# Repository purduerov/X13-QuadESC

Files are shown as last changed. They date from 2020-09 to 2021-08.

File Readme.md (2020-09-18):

# Readme for X13-QuadESC

Whenever you make a new part, download the datasheet and save it here _**and**_ with the part in the parts library

Always pull other people's changes before beginning to work
`git pull`

Be sure to push your changes after  working on them. Run:
1. `git add .` to add any files in this directory or a subdirectory
or `git add -u` to add any modified files
2. (Optional) `git clean -nX` to see what ignored files can be removed
	`git clean -fX` removes ignored files (Eagle backups)
3. `git commit -m "helpful commit message"` with a description of the work that you did
4. `git push` to push your work to github

Other helpful commands
* `git status` says information about modified and staged files
* `git log` shows the recent commits of the repository
* `git log filename.extension` show the recent commits for just that file
* `git checkout first-couple-letter-of-commit-id` lets you go back to a previous version
* `git checkout master` brings you back to the latest commit
* `git tag` lists the tags
* `git tag -a orderX -m "the version of the board placed for the X'th order"` tag a specific commit
* `git push --tags` needed to push tags to remote
* `git show orderX` show the commit log for the given tag
* `git checkout orderX` go back and interact with the files at the tagged commit

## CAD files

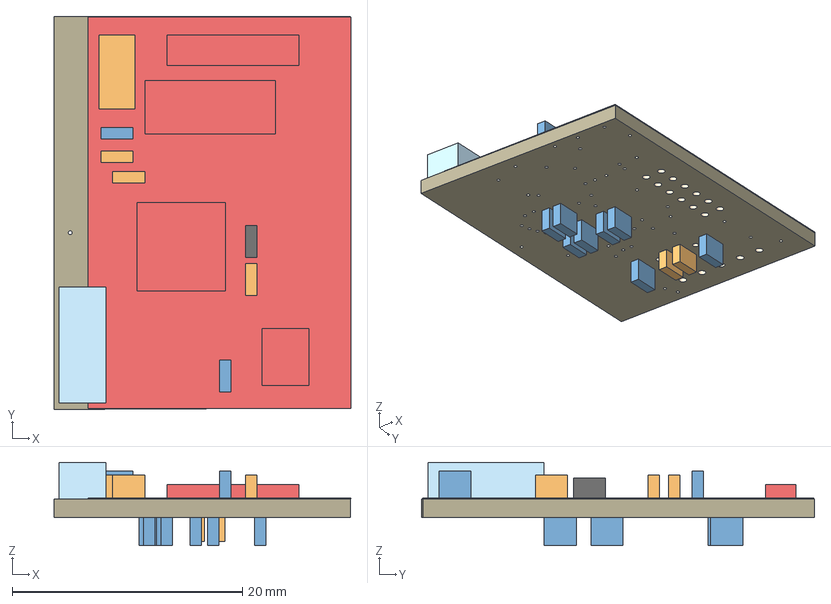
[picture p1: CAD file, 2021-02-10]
Quad_ESC_controller.step
25.8 x 34.2 x 7.23 mm
Board
20pF x 10
LED-0603
10k x 5
DISCRETECOMPONENTS_SWITCH
FE05-1
STM32F042K6T6
TCAN337D
ECS-80-S-4X
JST-8PIN
BACKPLANE_CONNECTORSESC

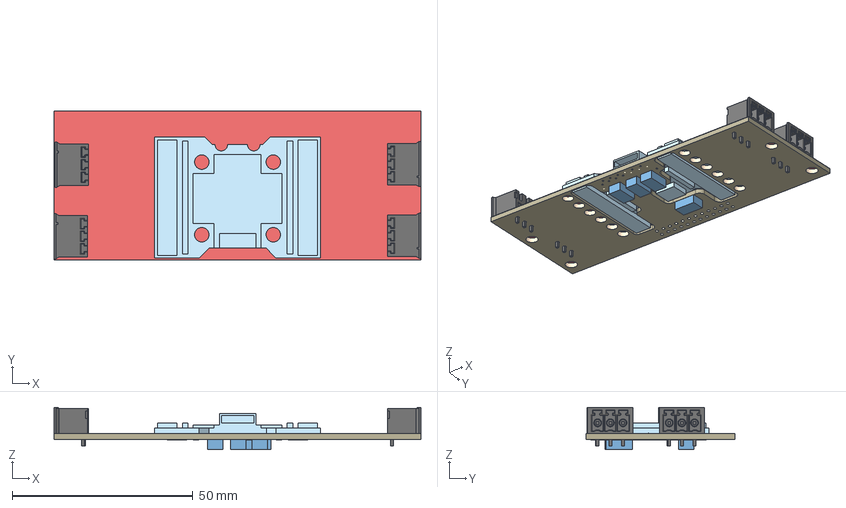
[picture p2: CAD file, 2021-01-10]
Quad_ESC_adapter.step
101.6 x 41.1 x 11.6 mm
Board
LUMENIER_QUAD
150uF x 4
6-32-HOLE x 4
BACKPLANE_ESC_ADAPTER_PWRESC

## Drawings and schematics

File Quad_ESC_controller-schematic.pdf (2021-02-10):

# GND ⁺³V³ +3V³

A

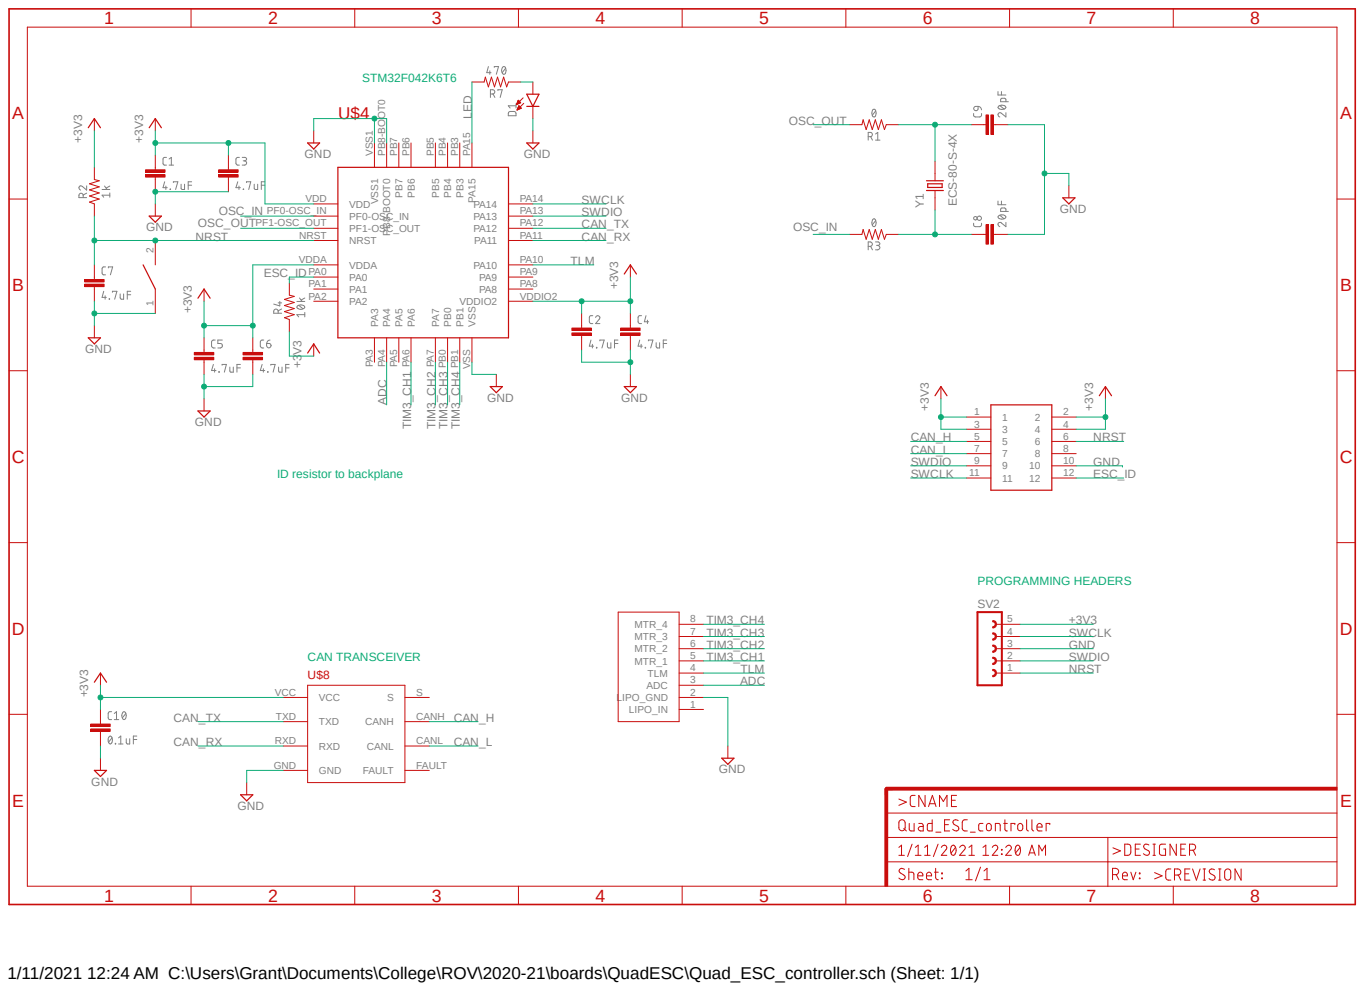
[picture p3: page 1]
GND; GND ⁺³V³ +3V³; GND +3V³; ECS⁻⁸⁰⁻S⁻⁴X; GND ⁺³V³; NRST NRST; PF1-OSC_OUT PF1-OSC_OUT; PF0-OSC_IN PF0-OSC_IN; VDD VDD; VDDA VDDA PA0 PA0 PA1 PA1; PA⁶ PA⁶ PA⁵ PA⁵ PA⁴ PA⁴ PA³ PA³; PA⁷ PA⁷ PB⁰ PB⁰ PB¹ PB¹ VSS VSS PA11; VDDIO2; VDDIO2 PB⁵ PB⁵ PB⁴ PB⁴ PB³ PB³ PA¹⁵ PA¹⁵ PB⁶ PB⁶ PB⁷ PB⁷ PB⁸⁻BOOT0 PB⁸⁻BOOT0 VSS¹ VSS¹ 1 2; VCC VCC; TXD TXD; RXD RXD; GND GND; CANH; CANL; FAULT; LIPO_IN; LIPO_GND; ADC; TLM; MTR_1; MTR_2; MTR_3; MTR_4; 12GND; CAN_TX; CAN_RX; TIM3_CH1 TIM³_CH¹; TIM3_CH2 TIM³_CH²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

STM32F042K6T6

ID resistor to backplane

1/11/2021 12:24 AM C:\Users\Grant\Documents\College\ROV\2020-21\boards\QuadESC\Quad_ESC_controller.sch (Sheet: 1/1)

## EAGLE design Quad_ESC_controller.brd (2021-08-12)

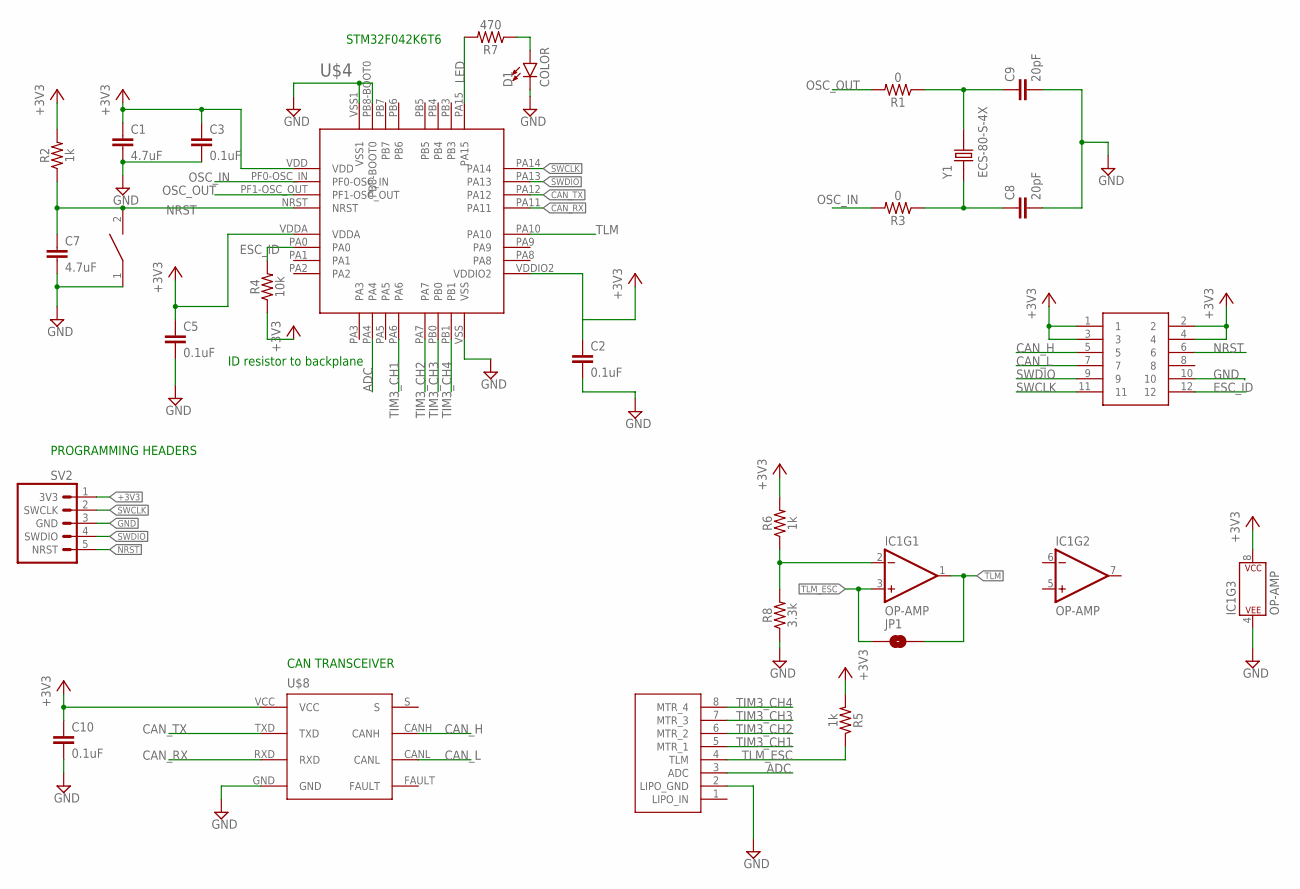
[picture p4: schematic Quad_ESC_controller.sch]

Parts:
C1, C7: 4.7uF; 0603
C2, C3, C5, C10: 0.1uF; 0603
C8, C9: 20pF; 0603
D1: COLOR; 0805
IC1: OP-AMP; SO08
JP1: JUMPER-SMT_2_NO_SILK; SMT-JUMPER_2_NO_SILK
R1, R3: 0; 0603
R2, R5, R6: 1k; 0603
R4: 10k; 0603
R7: 470; 0603
R8: 3.3k; 0603
RESET: DISCRETECOMPONENTS_SWITCH; DISCRETECOMPONENTS_SW_2512
SV2: 3V3 -SWCLK-GND-SWDIO- NRST; 1X05
U$2: JST-8PIN; 8PIN_CONNECTOR
U$3: BACKPLANE_CONNECTORSESC; BACKPLANE_CONNECTORS_ESC
U$4: STM32F042K6T6
U$8: TCAN337D
Y1: ECS-80-S-4X; XTAL_ECS-80-S-4X

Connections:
+3V3: C1.1, C2.1, C3.1, C5.1, C10.1, IC1.8 (P$V+), R2.2, R4.1, R5.2, R6.2, SV2.1 (3V3), U$3.1, U$3.2, U$3.3, U$3.4, U$4.VDD, U$4.VDDA, U$4.VDDIO2, U$8.VCC
ADC: U$2.3 (ADC), U$4.PA4
CAN_H: U$3.5, U$8.CANH
CAN_L: U$3.7, U$8.CANL
CAN_RX: U$4.PA11, U$8.RXD
CAN_TX: U$4.PA12, U$8.TXD
ESC_ID: R4.2, U$3.12, U$4.PA0
GND: C1.2, C2.2, C3.2, C5.2, C7.2, C8.2, C9.2, C10.2, D1.C, IC1.4 (P$V-), R8.1, RESET.1, SV2.3 (GND), U$2.2 (LIPO_GND), U$3.10, U$4.PB8-BOOT0, U$4.VSS, U$4.VSS1, U$8.GND
LED: R7.2, U$4.PA15
unnamed: C9.1, R1.1, Y1.2
unnamed: C8.1, R3.1, Y1.1
unnamed: IC1.2 (-IN), R6.1, R8.2
unnamed: D1.A, R7.1
NRST: C7.1, R2.1, RESET.2, SV2.5 (NRST), U$3.6, U$4.NRST
OSC_IN: R3.2, U$4.PF0-OSC_IN
OSC_OUT: R1.2, U$4.PF1-OSC_OUT
SWCLK: SV2.2 (SWCLK), U$3.11, U$4.PA14
SWDIO: SV2.4 (SWDIO), U$3.9, U$4.PA13
TIM3_CH1: U$2.5 (MTR_1), U$4.PA6
TIM3_CH2: U$2.6 (MTR_2), U$4.PA7
TIM3_CH3: U$2.7 (MTR_3), U$4.PB0
TIM3_CH4: U$2.8 (MTR_4), U$4.PB1
TLM: IC1.1 (OUT), JP1.2, U$4.PA10
TLM_ESC: IC1.3 (+IN), JP1.1, R5.1, U$2.4 (TLM)

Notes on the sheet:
STM32F042K6T6
PROGRAMMING HEADERS
CAN TRANSCEIVER
ID resistor to backplane

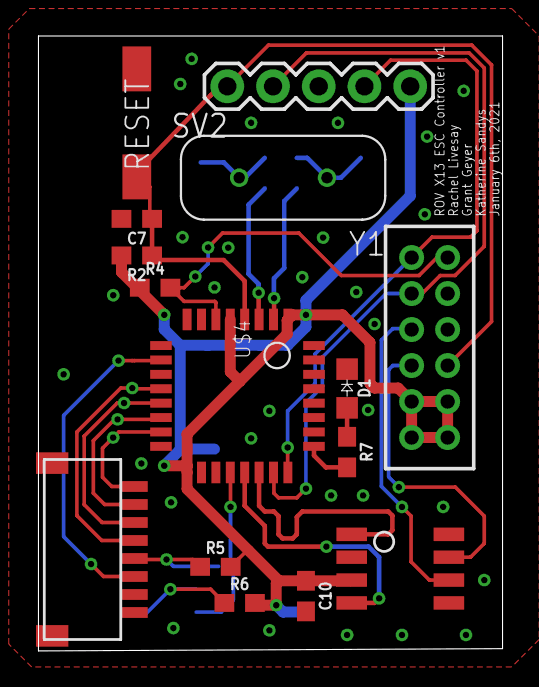
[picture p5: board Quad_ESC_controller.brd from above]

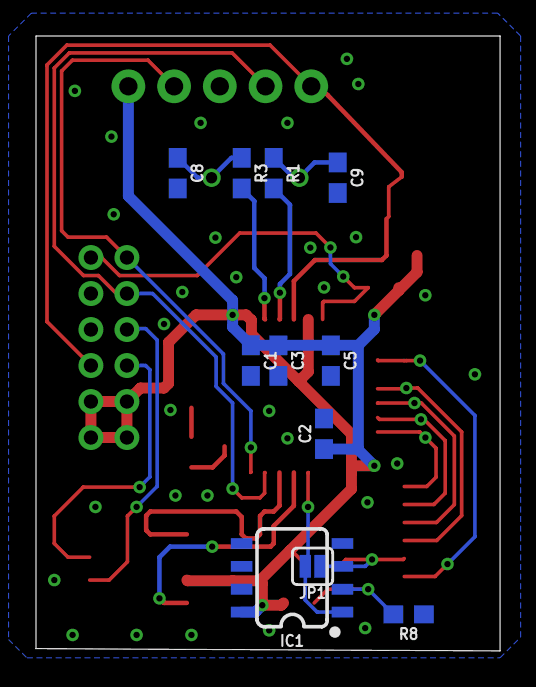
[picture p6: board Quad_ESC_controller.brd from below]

Board: 2 copper layers, 25.8 x 34.2 mm, 26 parts (11 on the bottom side), 24 nets.

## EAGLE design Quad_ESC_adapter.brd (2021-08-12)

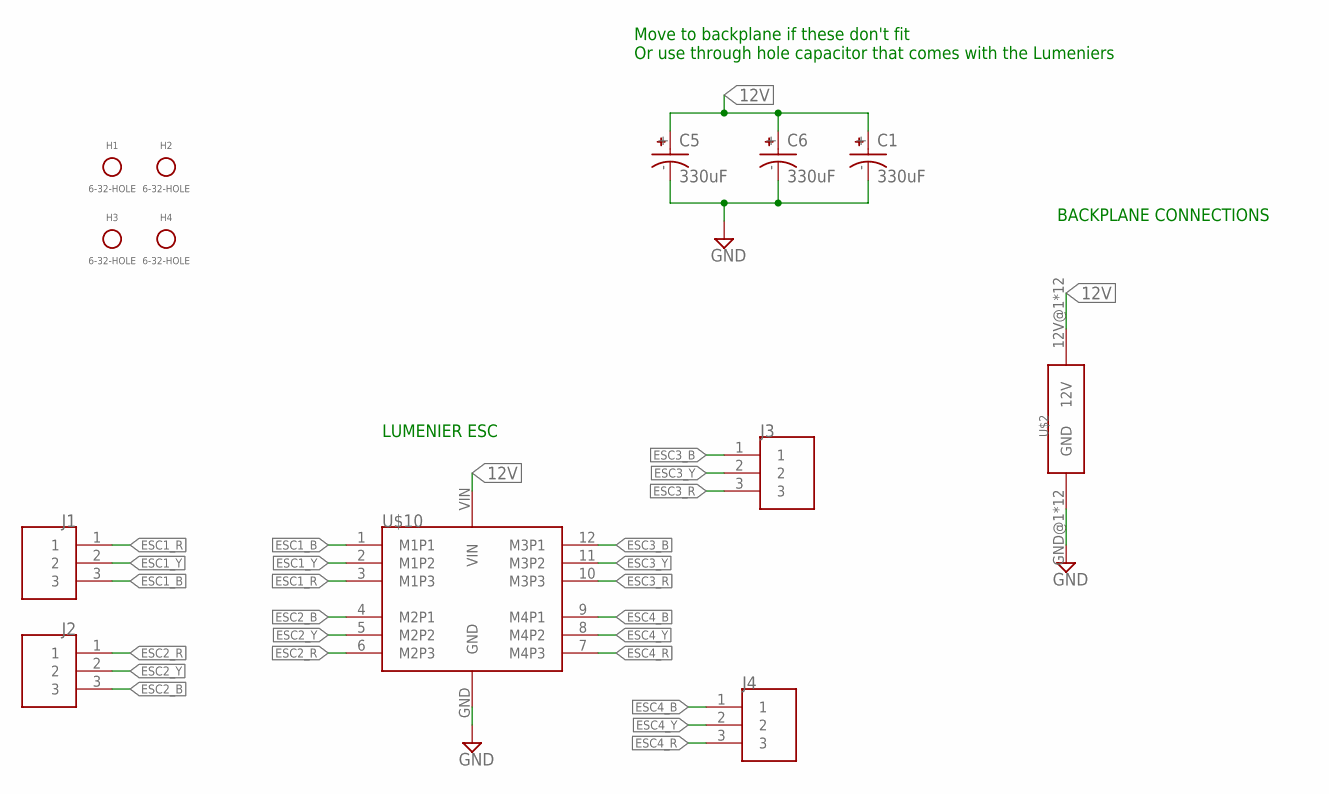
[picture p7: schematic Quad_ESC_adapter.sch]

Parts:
C1, C5, C6: 330uF; CAPAE1030X1050N
H1, H2, H3, H4: 6-32-HOLE
J1, J2, J3, J4: 284512-3
U$2: BACKPLANE_ESC_ADAPTER_PWRESC; BACKPLANE_ESC_ADAPTER_ESC_PWR
U$10: LUMENIER_QUAD-NO-CUT

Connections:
12V: C1.+, C5.+, C6.+, U$2.12V@1 (12V), U$2.12V@2 (12V), U$2.12V@3 (12V), U$2.12V@4 (12V), U$2.12V@5 (12V), U$2.12V@6 (12V), U$2.12V@7 (12V), U$2.12V@8 (12V), U$2.12V@9 (12V), U$2.12V@10 (12V), U$2.12V@11 (12V), U$2.12V@12 (12V), U$10.VIN
ESC1_B: J1.3, U$10.1 (M1P1)
ESC1_R: J1.1, U$10.3 (M1P3)
ESC1_Y: J1.2, U$10.2 (M1P2)
ESC2_B: J2.3, U$10.4 (M2P1)
ESC2_R: J2.1, U$10.6 (M2P3)
ESC2_Y: J2.2, U$10.5 (M2P2)
ESC3_B: J3.1, U$10.12 (M3P1)
ESC3_R: J3.3, U$10.10 (M3P3)
ESC3_Y: J3.2, U$10.11 (M3P2)
ESC4_B: J4.1, U$10.9 (M4P1)
ESC4_R: J4.3, U$10.7 (M4P3)
ESC4_Y: J4.2, U$10.8 (M4P2)
GND: C1.-, C5.-, C6.-, U$2.GND@1 (GND), U$2.GND@2 (GND), U$2.GND@3 (GND), U$2.GND@4 (GND), U$2.GND@5 (GND), U$2.GND@6 (GND), U$2.GND@7 (GND), U$2.GND@8 (GND), U$2.GND@9 (GND), U$2.GND@10 (GND), U$2.GND@11 (GND), U$2.GND@12 (GND), U$10.GND

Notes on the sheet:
BACKPLANE CONNECTIONS
LUMENIER ESC
Move to backplane if these don't fit Or use through hole capacitor that comes with the Lumeniers

Board: 2 copper layers, 13 parts (1 on the bottom side), 14 nets, no tracks yet.

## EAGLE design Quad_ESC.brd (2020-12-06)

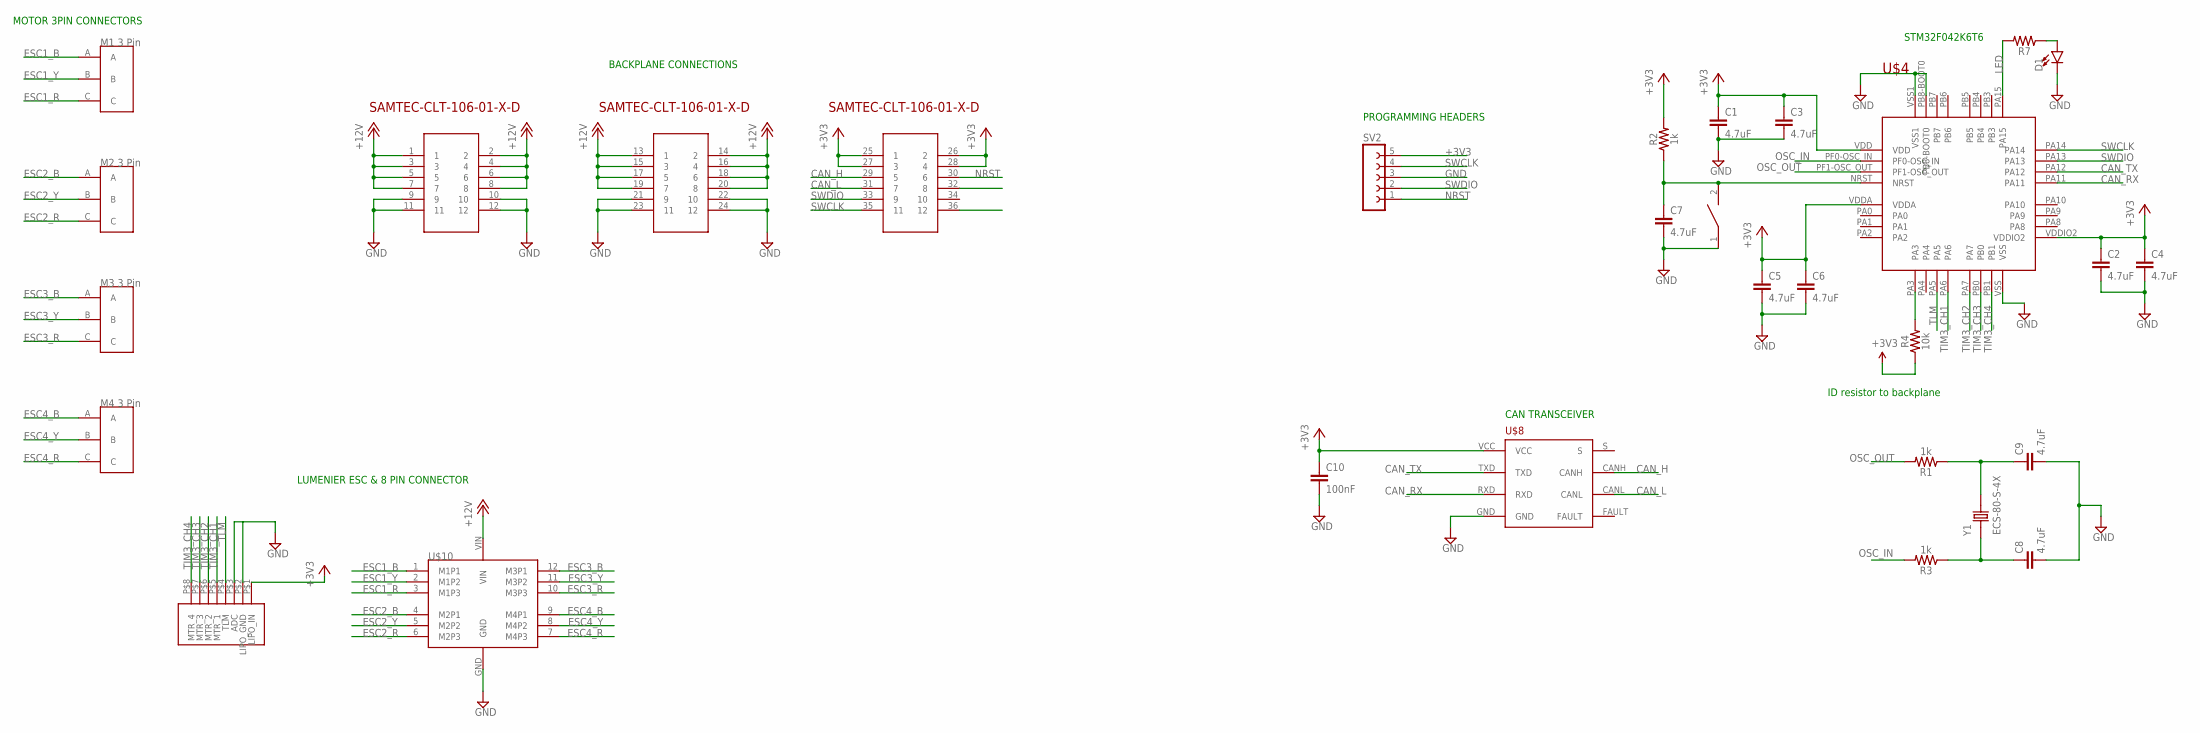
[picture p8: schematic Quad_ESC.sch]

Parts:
C1, C2, C3, C4, C5, C6, C7, C8, C9: 4.7uF; 0603
C10: 100nF; 0603
D1: LED0603; LED-0603
R1, R2, R3: 1k; 0603
R4: 10k; 0603
R7: 0603
RESET: SWITCH; SW_2512
SV2: FE05-1
U$1, U$5, U$6, U$7: 3PINCONNECTOR
U$2: 8PIN_CONNECTOR; 8PI_CONNECTOR
U$3: BACKPLANE_CONNECTORS
U$4: STM32F042K6T6
U$8: TCAN337D
U$10: LUMENIER_QUAD
Y1: ECS-80-S-4X; XTAL_ECS-80-S-4X

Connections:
+3V3: C1.1, C2.1, C3.1, C4.1, C5.1, C6.1, C10.1, R2.2, R4.1, SV2.5, U$2.P$1 (LIPO_IN), U$3.25 (1), U$3.26 (2), U$3.27 (3), U$3.28 (4), U$4.VDD, U$4.VDDA, U$4.VDDIO2, U$8.VCC
+12V: U$3.1, U$3.2, U$3.3, U$3.4, U$3.5, U$3.6, U$3.7, U$3.8, U$3.13 (1), U$3.14 (2), U$3.15 (3), U$3.16 (4), U$3.17 (5), U$3.18 (6), U$3.19 (7), U$3.20 (8), U$10.VIN
CAN_H: U$3.29 (5), U$8.CANH
CAN_L: U$3.31 (7), U$8.CANL
CAN_RX: U$4.PA11, U$8.RXD
CAN_TX: U$4.PA12, U$8.TXD
ESC1_B: U$1.A, U$10.1 (M1P1)
ESC1_R: U$1.C, U$10.3 (M1P3)
ESC1_Y: U$1.B, U$10.2 (M1P2)
ESC2_B: U$5.A, U$10.4 (M2P1)
ESC2_R: U$5.C, U$10.6 (M2P3)
ESC2_Y: U$5.B, U$10.5 (M2P2)
ESC3_B: U$6.A, U$10.12 (M3P1)
ESC3_R: U$6.C, U$10.10 (M3P3)
ESC3_Y: U$6.B, U$10.11 (M3P2)
ESC4_B: U$7.A, U$10.9 (M4P1)
ESC4_R: U$7.C, U$10.7 (M4P3)
ESC4_Y: U$7.B, U$10.8 (M4P2)
GND: C1.2, C2.2, C3.2, C4.2, C5.2, C6.2, C7.2, C8.2, C9.2, C10.2, D1.C, RESET.1, SV2.3, U$2.P$2 (LIPO_GND), U$2.P$3 (ADC), U$3.9, U$3.10, U$3.11, U$3.12, U$3.21 (9), U$3.22 (10), U$3.23 (11), U$3.24 (12), U$4.PB8-BOOT0, U$4.VSS, U$4.VSS1, U$8.GND, U$10.GND
LED: R7.2, U$4.PA15
unnamed: C9.1, R1.1, Y1.2
unnamed: C8.1, R3.1, Y1.1
unnamed: R4.2, U$4.PA3
unnamed: D1.A, R7.1
NRST: SV2.1, U$3.30 (6)
NRST1: C7.1, R2.1, RESET.2, U$4.NRST
OSC_IN: R3.2, U$4.PF0-OSC_IN
OSC_OUT: R1.2, U$4.PF1-OSC_OUT
SWCLK: SV2.4, U$3.35 (11), U$4.PA14
SWDIO: SV2.2, U$3.33 (9), U$4.PA13
TIM3_CH1: U$2.P$5 (MTR_1), U$4.PA6
TIM3_CH2: U$2.P$6 (MTR_2), U$4.PA7
TIM3_CH3: U$2.P$7 (MTR_3), U$4.PB0
TIM3_CH4: U$2.P$8 (MTR_4), U$4.PB1
TLM: U$2.P$4 (TLM), U$4.PA5

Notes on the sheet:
M1 3 Pin
M2 3 Pin
M3 3 Pin
M4 3 Pin
BACKPLANE CONNECTIONS
MOTOR 3PIN CONNECTORS
STM32F042K6T6
PROGRAMMING HEADERS
CAN TRANSCEIVER
LUMENIER ESC & 8 PIN CONNECTOR
ID resistor to backplane

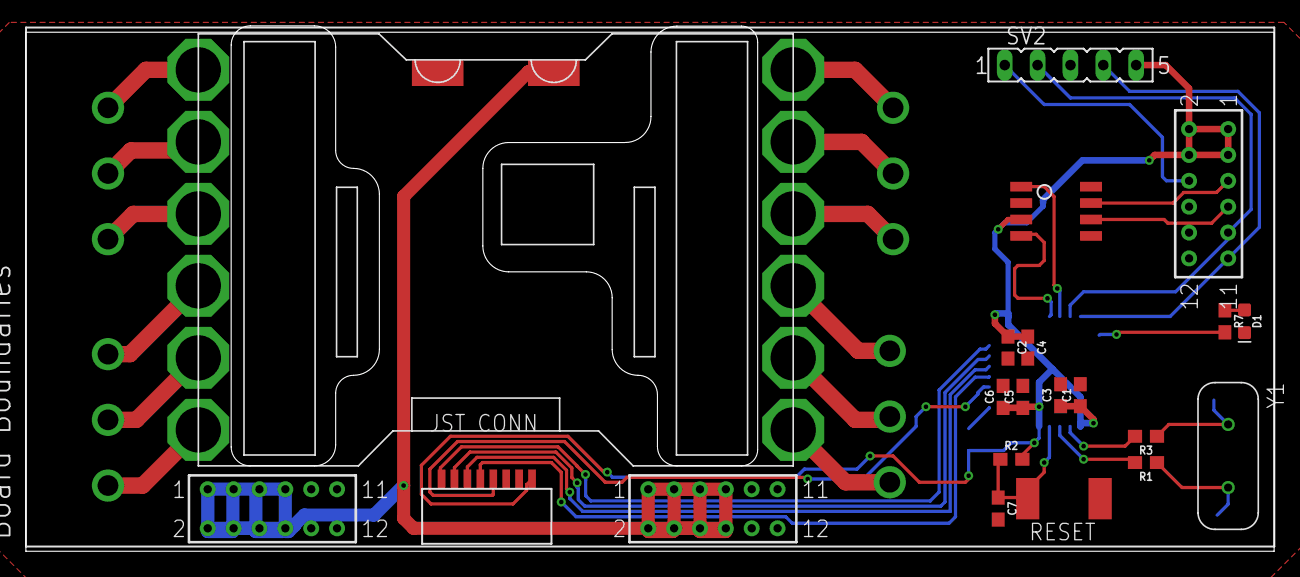
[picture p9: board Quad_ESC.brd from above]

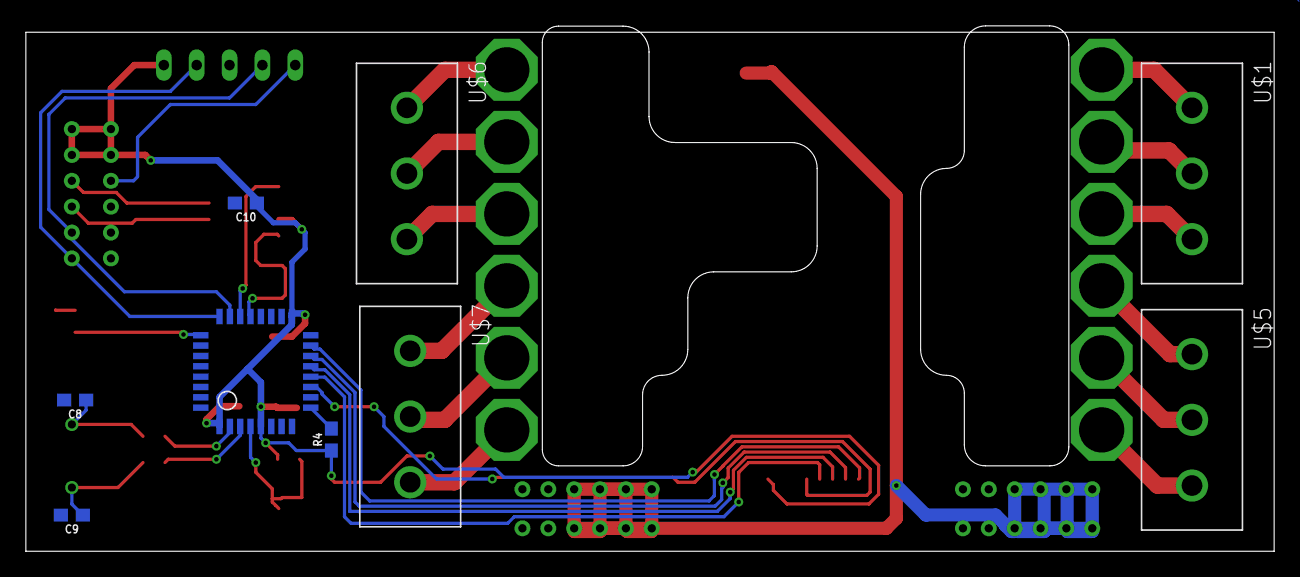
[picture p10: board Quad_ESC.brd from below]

Board: 2 copper layers, 96.5 x 40.1 mm, 28 parts (9 on the bottom side), 35 nets.

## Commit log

2020-10-10 Create Quad_ESC.sch
    created file, moved over parts from X12 version
    [Quad_ESC.sch]
2020-10-17 Lib Changes/Schem Update
    Added Cutouts/changed dimensions of ESC footprint in library; added board parts to library; tweaked schematic; created board file.
    [Quad_ESC.brd, Quad_ESC.sch]
2020-10-17 Lib Update (again)
    ok definitely did not push the wrong version of the library file last time haha
    [Quad_ESC.brd, Quad_ESC.sch]
2020-10-17 Lib Update/Sch Update
    Migrated 3 pin connectors from X-11 AFRO lib; fixed BLHeli symbol so labels no longer overlap; fixed connections and placement on schematic.
    [Quad_ESC.brd, Quad_ESC.sch]
2020-10-21 Board Update
    Added minor pin connections
    [Quad_ESC.brd, Quad_ESC.sch]
2020-10-24 Lib/Schem Update
    tweaked connections to STM chip; split esc device into lumenier ESC and 8 pin connector (need to figure out how to pair those still :/ ); scooted around components on schematic
    [Quad_ESC.brd, Quad_ESC.sch]
2020-10-25 turn off layer 93 (pins). Create correct dimension board
    [Quad_ESC.brd, Quad_ESC.sch]
2020-10-27 made board a little smaller
    [Quad_ESC.brd]
2020-11-12 Schem/Lib Update
    added new footprint to schematic and library, added ID resistor to chip, standardized symbols across schematic
    [Quad_ESC.brd, Quad_ESC.sch]
2020-11-14 Minor Sch Fixes/Board Placement
    Fixed issues with schematic and doubling of backplane connectors, precursory board placements and connections
    [Quad_ESC.brd, Quad_ESC.sch]
2020-11-14 Quick Board Update
    ripup; done for presentation, only placement of components present on board
    [Quad_ESC.brd]
2020-11-21 Board/Schem Update
    added CLT low profile samtec connectors to schem/board, looking at the connector spacing on the board stresses me out ;-;
    [Quad_ESC.brd, Quad_ESC.sch]
2020-11-21 Board Update
    actually put the connectors on the right side of the board this time haha
    [Quad_ESC.brd]
2020-12-02 Connector Update!!
    made new part for backplae connectors with proper spacing, updated schematic and board accordingly
    [Quad_ESC.brd, Quad_ESC.sch]
2020-12-03 Update BLHeli_32 45A.lbr
    Added boundary box to connectors part for backplane.
2020-12-06 Connector Updates, Board Routing
    Backplane connectors updated, board routing on right side completed
    [Quad_ESC.brd, Quad_ESC.sch]
2020-12-06 Signals fixed a bit?
    [Quad_ESC.brd]
2020-12-06 Board Update (again)
    [Quad_ESC.brd]
2020-12-06 Quick, Minor Changes
    [Quad_ESC.brd]
2021-01-03 remove lumenier and adjust size for controller
    [Quad_ESC_controller.brd, Quad_ESC_controller.sch]
2021-01-03 split into adapter board
    [Quad_ESC_adapter.brd, Quad_ESC_adapter.sch]
2021-01-04 complete connector placement
    [Quad_ESC_adapter.brd, Quad_ESC_adapter.sch]
2021-01-05 Export step file
    [Quad_ESC_adapter.step]
2021-01-06 Placement/Routing Update
    the board and sch are out of sync and i have no idea how they got that way h e l p
    [Quad_ESC_controller.brd, Quad_ESC_controller.sch]
2021-01-06 tented vias under lumenier
    [Quad_ESC_adapter.brd]
2021-01-06 routed wider board
    [Quad_ESC_adapter.brd, Quad_ESC_adapter.sch]
2021-01-07 Placement/Routing Update
    microcontroller movied to front, CAN signals length checked
    [Quad_ESC_controller.brd, Quad_ESC_controller.sch]
2021-01-07 Small Board Change
    forgot to trace length check the OSC in/out oops
    [Quad_ESC_controller.brd]
2021-01-07 Library Changes for Backplane :)
    [Quad_ESC_controller.brd, Quad_ESC_controller.sch]
2021-01-07 Routing Update
    rerouted new connector into board :)
    [Quad_ESC_controller.brd, Quad_ESC_controller.sch]
2021-01-07 Labels/Final Touches
    Added: Vias, Names/Date/Board Label, Kingsman Logo :D
    [Quad_ESC_controller.brd]
2021-01-08 routed with 2x12 block. Basically ready to order
    [Quad_ESC_adapter.brd, Quad_ESC_adapter.sch]
2021-01-09 single outline version
    [Quad_ESC_adapter.brd, Quad_ESC_adapter.sch]
2021-01-09 this has been the best graphic in the history of graphics, maybe ever
    [Quad_ESC_adapter.brd]
2021-01-10 Final Board Changes ✽-(ˆ▿ˆ)/✽
    thank god
    (changes: vias con. to GND, esc id/tlm connections, design moved, connector footprint replaced, font sizes changed)
    [Quad_ESC_controller.brd, Quad_ESC_controller.sch]
2021-01-10 JST part
    [Quad_ESC_controller.brd, Quad_ESC_controller.sch]
2021-01-10 exports for ordering
    [Quad_ESC_adapter.step, Quad_ESC_controller.step]
2021-01-11 Final Board Changes Pt. 2: Electric Boogaloo
    Changes: [ bumped out board 100mil to the left, flipped esc signals on micro, moved TLM to analog pin 10 on micro, rotated connector, and rerouted board. ]
    [Quad_ESC_controller.brd, Quad_ESC_controller.sch]
2021-01-11 re print schematic for controller
    [Quad_ESC_controller.brd, Quad_ESC_controller.step]
2021-01-25 Use new JST footprint with mechanical solder pads (for future reference/v2)
    [Quad_ESC_controller.brd, Quad_ESC_controller.sch]
2021-02-07 Labels on adapter board and enlarge cutout
    [Quad_ESC_adapter.brd]
2021-02-10 Added 1k Resistor TLM -> 3.3V
    also tried airwiring it lol. it's v bad, but that is next year's problem.
    [Quad_ESC_controller.brd, Quad_ESC_controller.sch]
2021-03-06 Library/Board Update
    Added t-stop to pads on esc connector :)
    [Quad_ESC_controller.brd, Quad_ESC_controller.sch]
2021-05-09 Add op amp for telemetry logic level fixing
    [Quad_ESC_controller.brd, Quad_ESC_controller.sch]
2021-05-24 New SWD programming connector
    [Quad_ESC_controller.brd, Quad_ESC_controller.sch]
2021-08-12 Use aluminum caps for the adapter board
    [Quad_ESC_adapter.brd, Quad_ESC_adapter.sch, Quad_ESC_controller.brd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]

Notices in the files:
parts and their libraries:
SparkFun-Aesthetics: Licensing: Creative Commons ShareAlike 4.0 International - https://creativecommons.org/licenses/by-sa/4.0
